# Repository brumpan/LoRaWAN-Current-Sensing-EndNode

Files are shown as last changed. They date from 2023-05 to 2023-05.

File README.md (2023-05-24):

# LoRaWAN-Current-Sensing-EndNode

Traditionally, remote monitoring has been done using wired communications technologies such as ethernet and fiberoptics. In the last decade, low power narrow band radio communications technologies, such as LoRaWAN, have enabled wireless remote monitoring in microgrids.  Installing remote monitoring systems can be very costly using both wired or wireless communication schemes. Wired connections are expensive during installation and wireless connections are expensive during operation due to service subscriptions and may also require pre-existing infrastructure to operate. This project provides a modular solution for monitoring power output from photovoltaic panels remotely.

This page contains the design files and software for a current-sensing end node for photovoltaic panels in microgrids using the LoRaWAN network.

# Dependencies

https://github.com/ElectronicCats/Beelan-LoRaWAN.git

https://github.com/earlephilhower/arduino-pico.git

# Credits

This project constitutes partial fulfillment of the Senior Project Capstone, a prerequisite for obtaining a Bachelor's degree in Electrical Engineering from The Oregon Institute of Technology.

Project Members: Brendan Dickerson & Leo Zenuhin

Spring 2023

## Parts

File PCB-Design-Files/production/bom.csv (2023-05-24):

Designator | Footprint | Quantity | Value | LCSC Part #
C1, C2 | 402 | 2 | 27p
C10, C12, C22, C23, C25, C26, C4, C6, C7, C9 | 402 | 10 | 100n
C11, C3, C8 | 402 | 3 | 2.2u
C13, C5 | 402 | 2 | 1u
C14, C16, C24 | 805 | 3 | 10u
C15 | 805 | 1 | 4.7u
C17, C18 | 402 | 2 | 1n
C19, C20 | 402 | 2 | 6.8n
C21 | 402 | 1 | 220n
C27 | CP_Elec_6.3x7.7 | 1 | 22u
D1, D3 | 805 | 2 | LED
D2, D4, D7, D8 | D_SOD-123 | 4 | B220
D6 | 805 | 1 | PWR
F1 | 805 | 1 | 6V 0.5A
Q1, Q2 | SOT-23 | 2 | BSS84
Q3 | SOT-23 | 1 | BSS123
R1, R10, R11, R22, R23, R6, R7, R8, R9 | 402 | 9 | 10k
R12 | 402 | 1 | 1.18k
R13 | 402 | 1 | 1.13k
R14 | R_Axial_DIN0411_L9.9mm_D3.6mm_P15.24mm_Horizontal | 1 | 220
R15, R16, R24 | 402 | 3 | 470
R17 | 402 | 1 | 100k
R18, R25, R4, R5 | 402 | 4 | 1k
R19_2 | 805 | 1 | 47
R19 | 402 | 1 | 47
R2, R3 | 402 | 2 | 27
R20, R21 | 402 | 2 | 4.7K
SW1 | SW_PUSH_6mm | 1 | Select
SW2 | SW_DIP_SPSTx08_Slide_6.7x21.88mm_W7.62mm_P2.54mm_LowProfile | 1 | SW_DIP_x08
SW3 | SW_PUSH_6mm | 1 | Bootsel
U1 | QFN-56-1EP_7x7mm_P0.4mm_EP3.2x3.2mm | 1 | RP2040
U2 | SOIC-16_3.9x9.9mm_P1.27mm | 1 | 74HC165
U3 | VQFN-16-1EP_3x3mm_P0.5mm_EP1.6x1.6mm | 1 | BQ24072RGT
U5 | SOIC-8_5.23x5.23mm_P1.27mm | 1 | W25Q128JVS
U6 | SOT-223-3_TabPin2 | 1 | AMS1117-3.3

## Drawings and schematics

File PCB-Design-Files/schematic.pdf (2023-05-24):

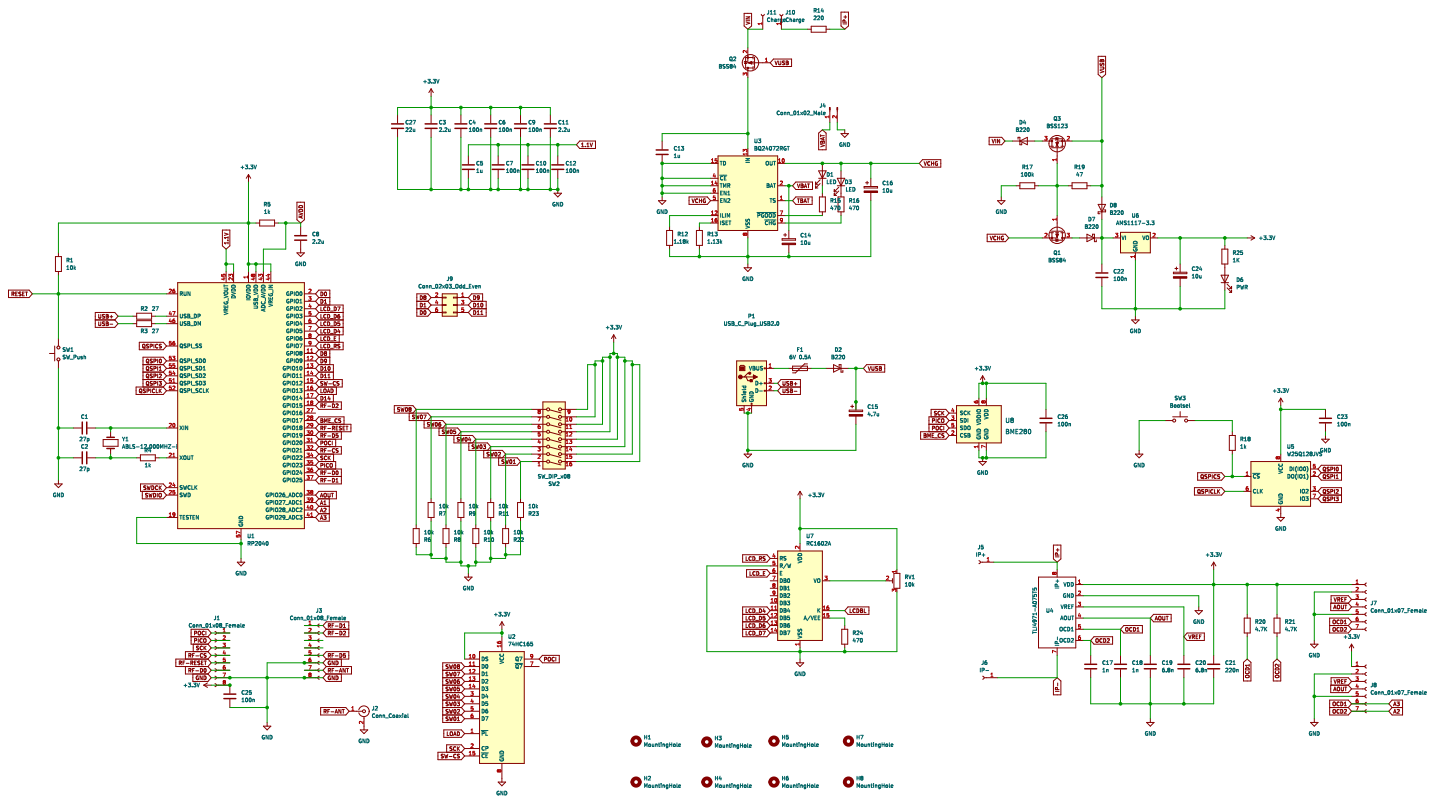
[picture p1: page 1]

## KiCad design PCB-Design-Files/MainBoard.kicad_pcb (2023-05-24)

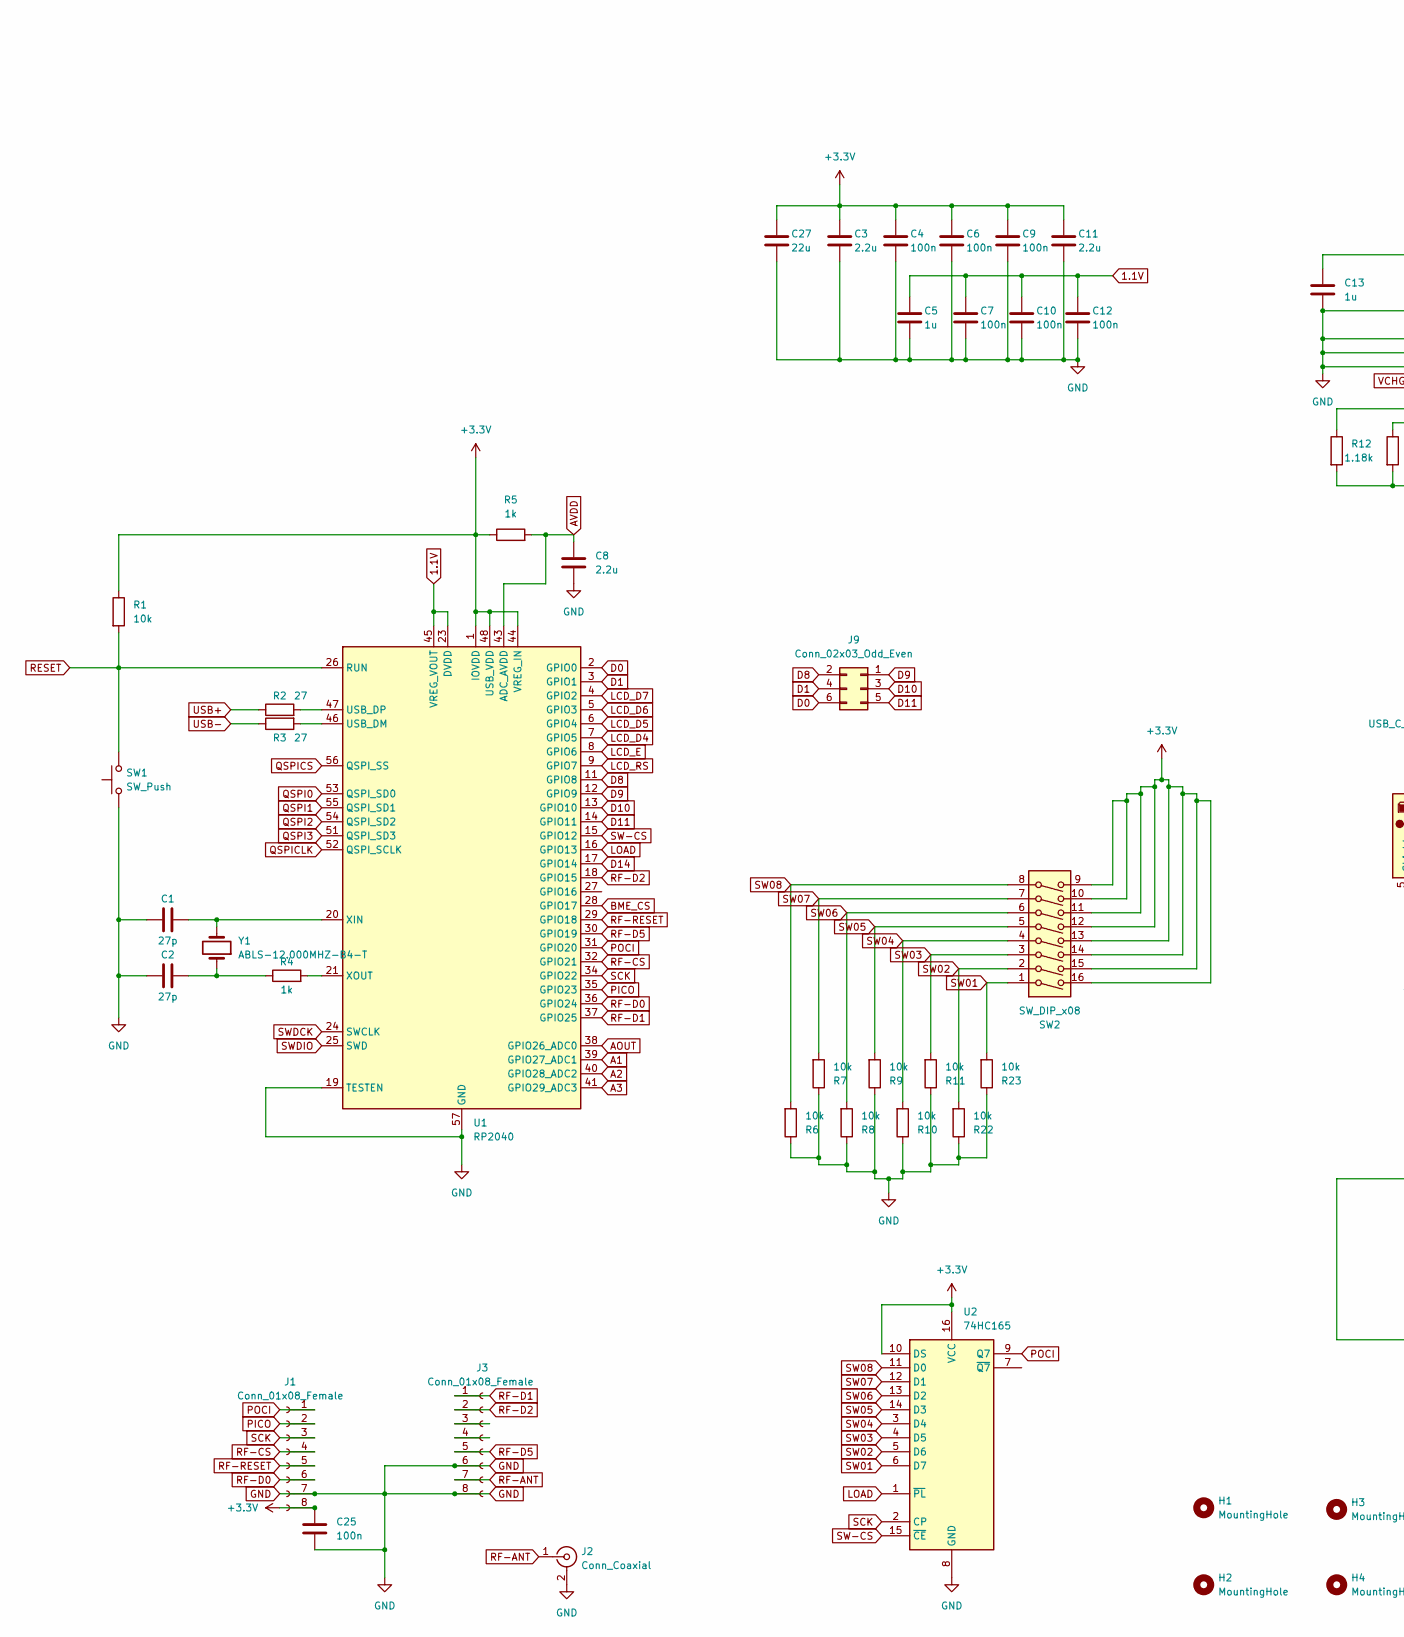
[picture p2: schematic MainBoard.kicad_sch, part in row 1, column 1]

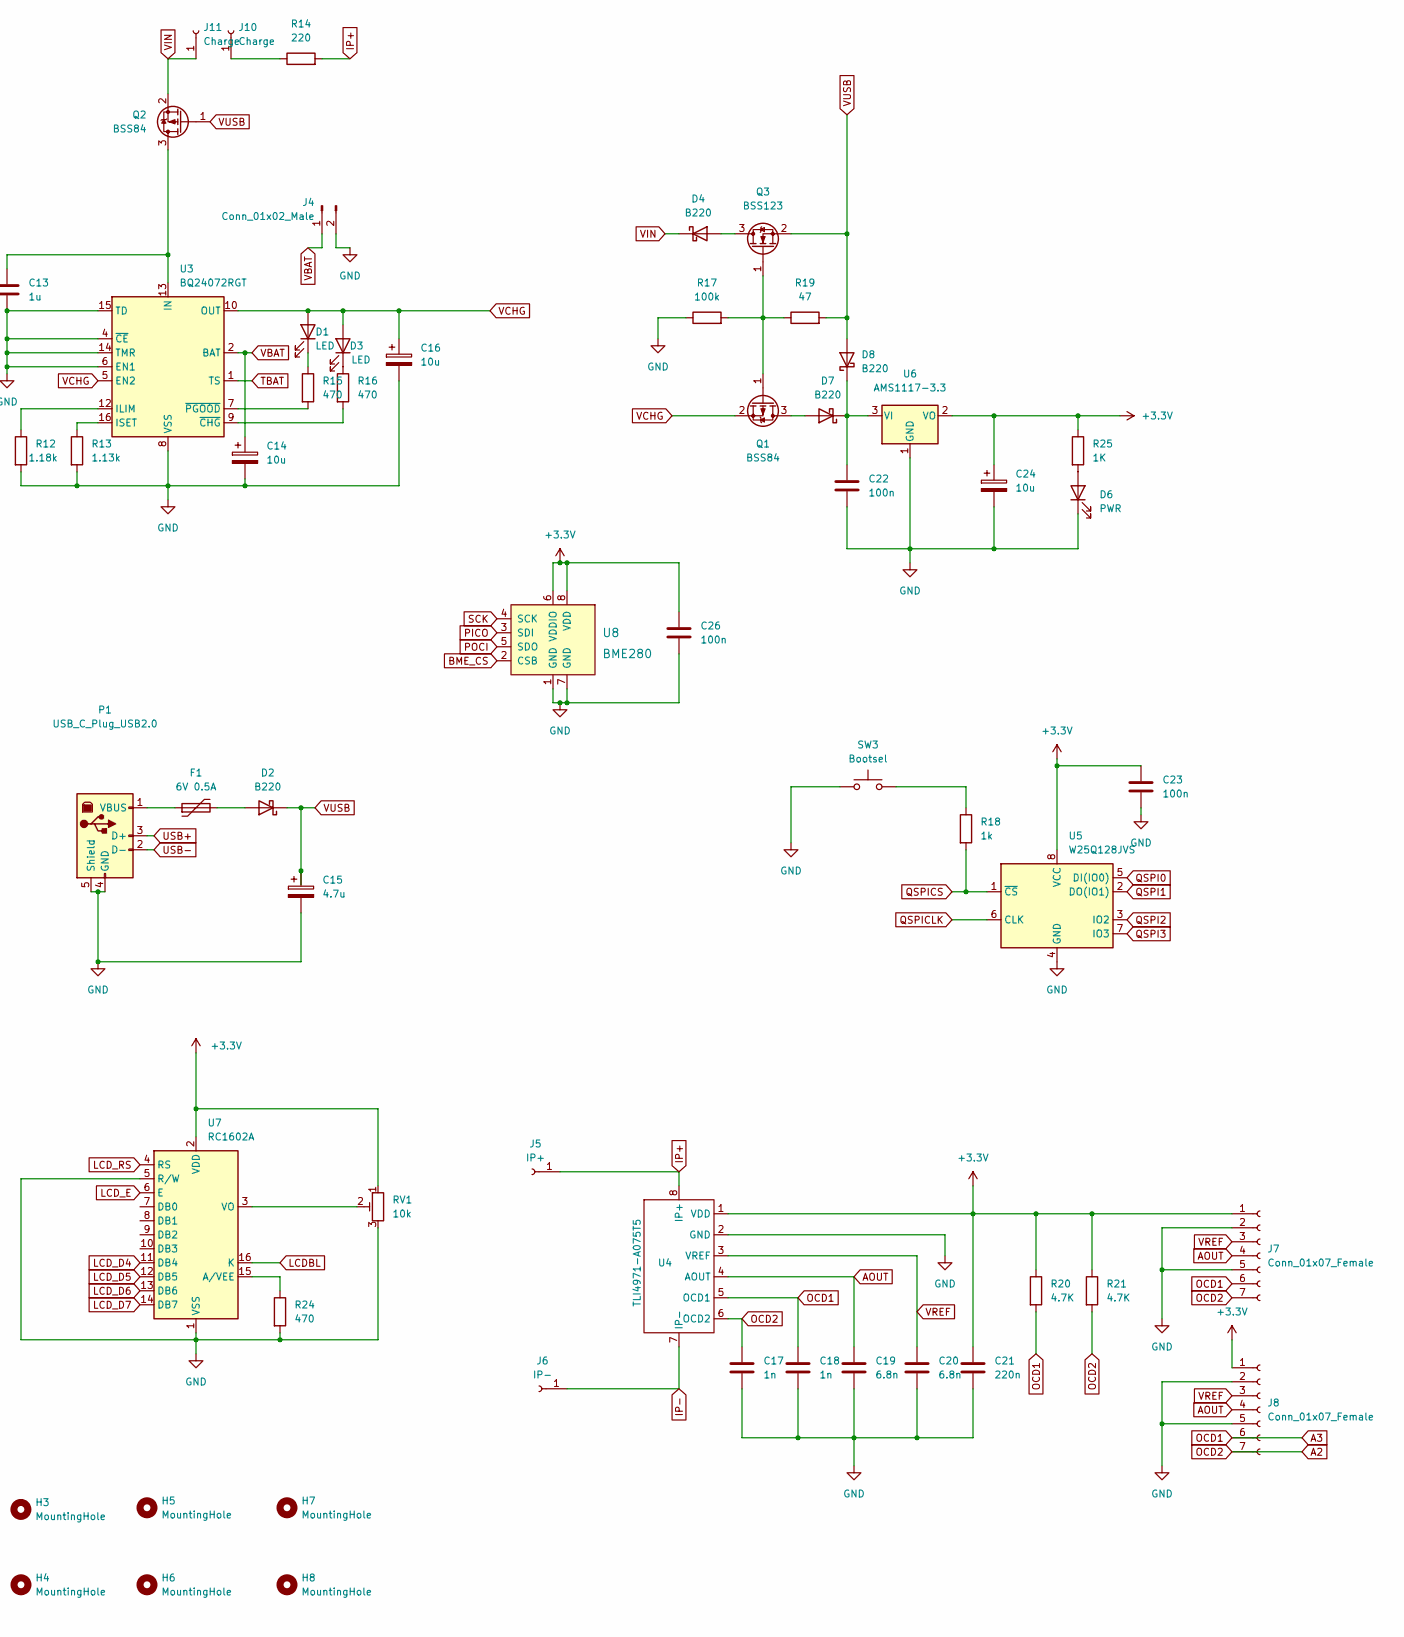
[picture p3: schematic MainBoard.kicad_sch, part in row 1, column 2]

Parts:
C1, C2: 27p; C_0402_1005Metric
C3, C8, C11: 2.2u; C_0402_1005Metric
C4, C6, C7, C9, C10, C12, C22, C23, C25, C26: 100n; C_0402_1005Metric
C5, C13: 1u; C_0402_1005Metric
C14, C16, C24: 10u; C_0805_2012Metric
C15: 4.7u; C_0805_2012Metric
C17, C18: 1n; C_0402_1005Metric
C19, C20: 6.8n; C_0402_1005Metric
C21: 220n; C_0402_1005Metric
C27: 22u; CP_Elec_6.3x7.7
D1, D3: LED; LED_0805_2012Metric
D2, D4, D7, D8: B220; D_SOD-123
D6: PWR; LED_0805_2012Metric
F1: 6V 0.5A; Fuse_0805_2012Metric
H1, H2, H3, H4, H5, H6, H7, H8: MountingHole; MountingHole_2.2mm_M2
J1, J3: Conn_01x08_Female; PinHeader_1x08_P2.54mm_Vertical
J2: Conn_Coaxial; U.FL_Molex_MCRF_73412-0110_Vertical
J4: Conn_01x02_Male; JST_PH_S2B-PH-K_1x02_P2.00mm_Horizontal
J5: IP+; Wuerth_REDCUBE-THR_WP-THRSH_74651195_THR
J6: IP-; Wuerth_REDCUBE-THR_WP-THRSH_74651195_THR
J7, J8: Conn_01x07_Female; PinHeader_1x07_P2.54mm_Vertical
J9: Conn_02x03_Odd_Even; PinSocket_2x03_P2.54mm_Vertical
J10, J11: Charge; PinSocket_1x01_P2.54mm_Vertical
P1: USB_C_Plug_USB2.0; USB_B_OST_USB-B1HSxx_Horizontal
Q1, Q2: BSS84; SOT-23
Q3: BSS123; SOT-23
R1, R6, R7, R8, R9, R10, R11, R22, R23: 10k; R_0402_1005Metric
R2, R3: 27; R_0402_1005Metric
R4, R5, R18: 1k; R_0402_1005Metric
R12: 1.18k; R_0402_1005Metric
R13: 1.13k; R_0402_1005Metric
R14: 220; R_Axial_DIN0617_L17.0mm_D6.0mm_P30.48mm_Horizontal
R15, R16, R24: 470; R_0402_1005Metric
R17: 100k; R_0402_1005Metric
R19: 47; R_0402_1005Metric
R20, R21: 4.7K; R_0402_1005Metric
R25: 1K; R_0402_1005Metric
RV1: 10k; Potentiometer_Bourns_3296Y_Vertical
SW1: SW_Push; SW_PUSH_6mm
SW2: SW_DIP_x08; SW_DIP_SPSTx08_Slide_6.7x21.88mm_W7.62mm_P2.54mm_LowProfile
SW3: Bootsel; SW_PUSH_6mm
U1: RP2040; QFN-56-1EP_7x7mm_P0.4mm_EP3.2x3.2mm
U2: 74HC165; SOIC-16_3.9x9.9mm_P1.27mm
U3: BQ24072RGT; VQFN-16-1EP_3x3mm_P0.5mm_EP1.6x1.6mm
U4: TLI4971-A075T5; Infineon_PG-TISON-8-5
U5: W25Q128JVS; SOIC-8_5.23x5.23mm_P1.27mm
U6: AMS1117-3.3; SOT-223-3_TabPin2
U7: RC1602A
U8: BME280; Pressure_Sensor_LGA-8_2.5x2.5mm_BME280; MPN BME280; Digi-Key_PN 828-1063-1-ND
Y1: ABLS-12.000MHZ-B4-T; Crystal_HC49-U_Vertical

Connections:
1.1V: C5.1, C7.1, C10.1, C12.1, U1.23 (DVDD), U1.45 (VREG_VOUT), U1.50 (DVDD)
+3.3V: C3.1, C4.1, C6.1, C9.1, C11.1, C21.1, C23.1, C24.1, C25.1, C26.1, C27.1, J1.8, J7.1, J8.1, R1.1, R5.1, R20.1, R21.1, R25.1, RV1.1, SW2.9, SW2.10, SW2.11, SW2.12, SW2.13, SW2.14, SW2.15, SW2.16, U1.1 (IOVDD), U1.10 (IOVDD), U1.22 (IOVDD), U1.33 (IOVDD), U1.42 (IOVDD), U1.44 (VREG_IN), U1.48 (USB_VDD), U1.49 (IOVDD), U2.10 (DS), U2.16 (VCC), U4.1 (VDD), U5.8 (VCC), U6.2 (VO), U7.2 (VDD), U8.6 (VDDIO), U8.8 (VDD); also elsewhere on the board
A1: U1.39 (GPIO27_ADC1)
A2: C17.1, J7.7, J8.7, R21.2, U1.40 (GPIO28_ADC2), U4.6 (OCD2)
A3: C18.1, J7.6, J8.6, R20.2, U1.41 (GPIO29_ADC3), U4.5 (OCD1)
AOUT: C19.1, J7.4, J8.4, U1.38 (GPIO26_ADC0), U4.4 (AOUT)
AVDD: C8.1, R5.2, U1.43 (ADC_AVDD)
BME_CS: U1.28 (GPIO17), U8.2 (CSB)
D0: J9.6, U1.2 (GPIO0)
D1: J9.4, U1.3 (GPIO1)
D8: J9.2, U1.11 (GPIO8); also elsewhere on the board
D9: J9.1, U1.12 (GPIO9)
D10: J9.3, U1.13 (GPIO10)
D11: J9.5, U1.14 (GPIO11)
D14: U1.17 (GPIO14)
IP+: J5.1, R14.2, U4.8 (IP+)
IP-: J6.1, U4.7 (IP-)
LCDBL: U7.16 (K)
LCD_D4: U1.7 (GPIO5), U7.11 (DB4)
LCD_D5: U1.6 (GPIO4), U7.12 (DB5)
LCD_D6: U1.5 (GPIO3), U7.13 (DB6)
LCD_D7: U1.4 (GPIO2), U7.14 (DB7)
LCD_E: U1.8 (GPIO6), U7.6 (E)
LCD_RS: U1.9 (GPIO7), U7.4 (RS)
LOAD: U1.16 (GPIO13), U2.1 (~PL)
unnamed: C1.2, U1.20 (XIN), Y1.2
unnamed: C2.2, R4.1, Y1.1
unnamed: C13.1, Q2.3 (D), U3.13 (IN)
unnamed: C22.1, D7.1 (K), D8.1 (K), U6.3 (VI)
unnamed: D1.1 (K), R15.1
unnamed: D2.2 (A), F1.2
unnamed: D3.1 (K), R16.1
unnamed: D4.2 (A), Q3.3 (D)
unnamed: D6.2 (A), R25.2
unnamed: D7.2 (A), Q1.3 (D)
unnamed: F1.1, P1.1 (VBUS)
unnamed: J10.1, R14.1
unnamed: R2.2, U1.47 (USB_DP)
unnamed: R3.2, U1.46 (USB_DM)
unnamed: R4.2, U1.21 (XOUT)
unnamed: R12.1, U3.12 (ILIM)
unnamed: R13.1, U3.16 (ISET)
unnamed: R15.2, U3.7 (~PGOOD)
unnamed: R16.2, U3.9 (~CHG)
unnamed: R18.1, SW3.2
unnamed: R24.1, U7.15 (A/VEE)
unnamed: RV1.2, U7.3 (VO)
PICO: J1.2, U1.35 (GPIO23), U8.3 (SDI)
POCI: J1.1, U1.31 (GPIO20), U2.9 (Q7), U8.5 (SDO)
QSPI0: U1.53 (QSPI_SD0), U5.5 (DI(IO0))
QSPI1: U1.55 (QSPI_SD1), U5.2 (DO(IO1))
QSPI2: U1.54 (QSPI_SD2), U5.3 (IO2)
QSPI3: U1.51 (QSPI_SD3), U5.7 (IO3)
QSPICLK: U1.52 (QSPI_SCLK), U5.6 (CLK)
QSPICS: R18.2, U1.56 (QSPI_SS), U5.1 (~CS)
RESET: R1.2, SW1.2, U1.26 (RUN)
RF-ANT: J2.1 (In), J3.7
RF-CS: J1.4, U1.32 (GPIO21)
RF-D0: J1.6, U1.36 (GPIO24)
RF-D1: J3.1, U1.37 (GPIO25)
RF-D2: J3.2, U1.18 (GPIO15)
RF-D5: J3.5, U1.30 (GPIO19)
RF-RESET: J1.5, U1.29 (GPIO18)
SCK: J1.3, U1.34 (GPIO22), U2.2 (CP), U8.4 (SCK)
SW01: R23.2, SW2.1, U2.6 (D7)
SW02: R22.2, SW2.2, U2.5 (D6)
SW03: R11.2, SW2.3, U2.4 (D5)
SW04: R10.2, SW2.4, U2.3 (D4)
SW05: R9.2, SW2.5, U2.14 (D3)
SW06: R8.2, SW2.6, U2.13 (D2)
SW07: R7.2, SW2.7, U2.12 (D1)
SW08: R6.2, SW2.8, U2.11 (D0)
SW-CS: U1.15 (GPIO12), U2.15 (~CE)
SWDCK: U1.24 (SWCLK)
SWDIO: U1.25 (SWD)
TBAT: U3.1 (TS)
USB+: P1.3 (D+), R2.1
USB-: P1.2 (D-), R3.1
VBAT: C14.1, J4.1, U3.2 (BAT), U3.3 (BAT)
VCHG: C16.1, D1.2 (A), D3.2 (A), Q1.2 (S), U3.5 (EN2), U3.10 (OUT), U3.11 (OUT)
VREF: C20.1, J7.3, J8.3, U4.3 (VREF)

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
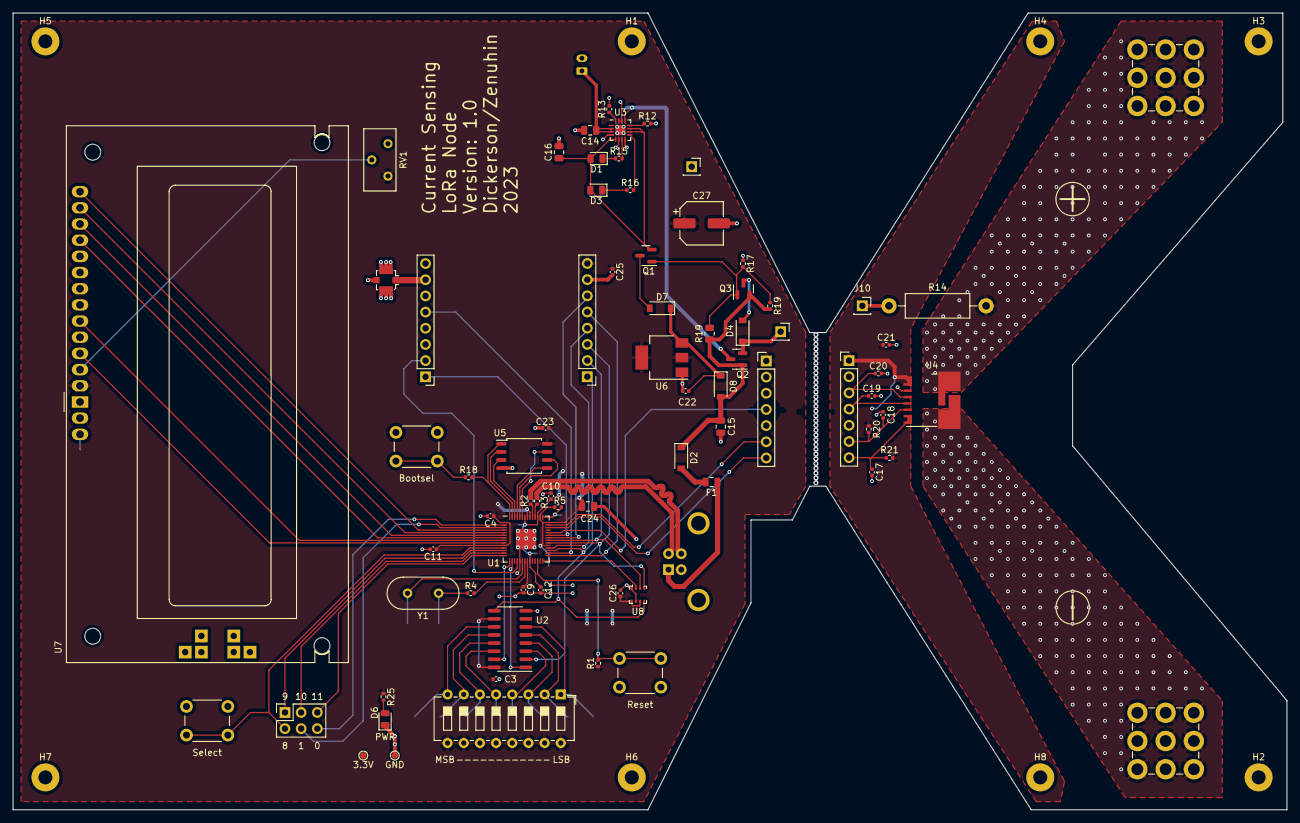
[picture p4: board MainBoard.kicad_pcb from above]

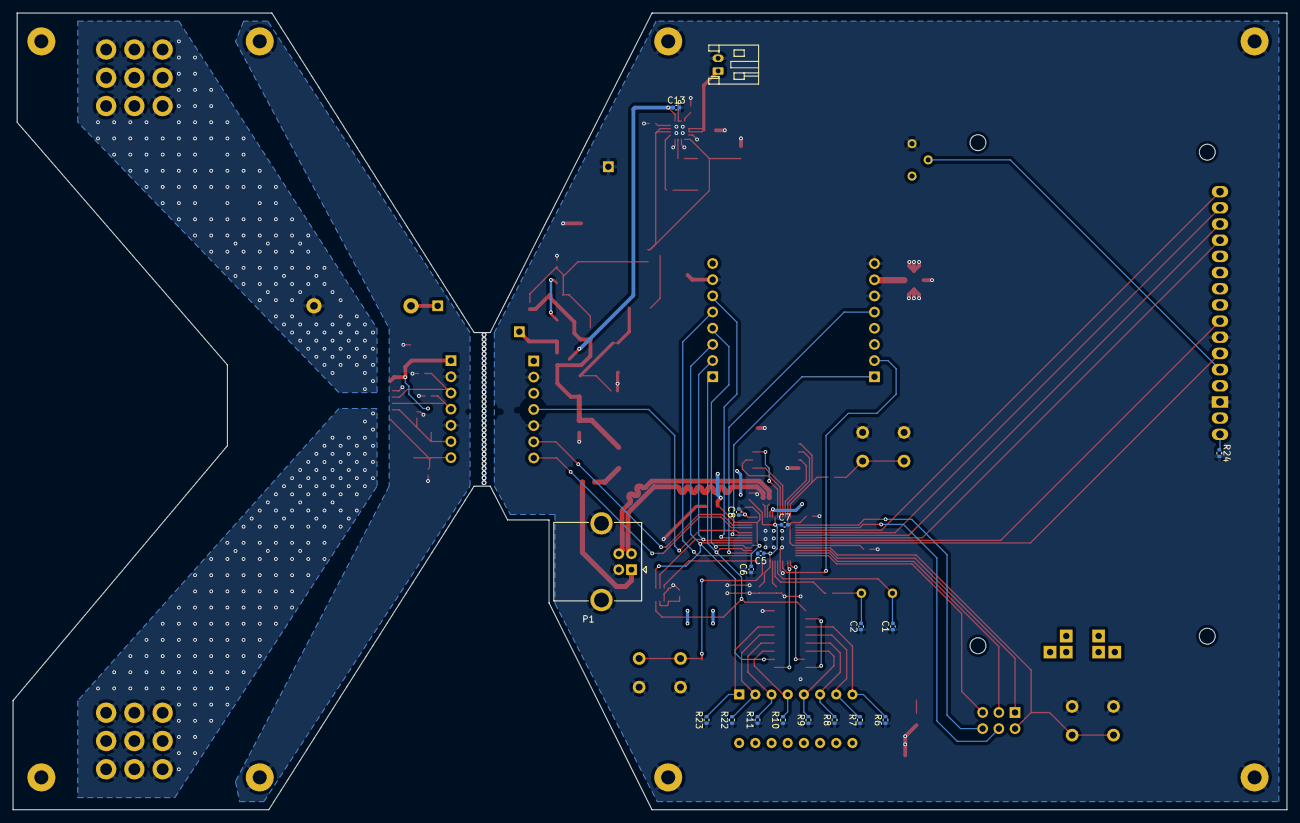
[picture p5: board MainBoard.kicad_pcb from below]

Board: 2 copper layers, 200.0 x 125.1 mm, 101 parts (18 on the bottom side), 79 nets.

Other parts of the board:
3.3V: TestPoint_Pad_D1.0mm
GND: TestPoint_Pad_D1.0mm
J11#2: Charge; PinSocket_1x01_P2.54mm_Vertical
R19#2: 47; R_0402_1005Metric
SW1#2: Select; SW_PUSH_6mm

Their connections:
+3.3V: 3.3V.1; also elsewhere on the board
D8: SW1#2.1; also elsewhere on the board

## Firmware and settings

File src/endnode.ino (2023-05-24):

#include <Adafruit_BME280.h>
#include <LiquidCrystal.h>
#include <lorawan.h>
#include <SPI.h>
#include <TLI4971.h>

/***************************************************************

- File:   endnode.ino
- Author: Brendan Dickerson
- Date:   2023-05-31
- Course: Capstone Project Spring 2023
- School: Oregon Institue of Technology
- Description:
    End node takes an analog current reading, environment status,
    and additional information and transmits it back to a 
    LoraWAN gateway. Typical applications for this include
    remote alternative energy sources such as photovoltaic 
    installations or wind energy farms. 

****************************************************************/

// RP2040 pin definitions
#define D0      0
#define D1      1
#define LCD_D7  2
#define LCD_D6  3
#define LCD_D5  4
#define LCD_D4  5
#define LCD_E   6
#define LCD_RS  7
#define SELBTN  8
#define TXLED   9
#define LCDBL   10
#define D11     11
#define SW_CS   12
#define LOAD    13
#define D14     14
#define RF_D2   15
#define BME_CS  17
#define RF_RES  18
#define RF_D5   19
#define POCI    20
#define RF_CS   21
#define SCK     22
#define PICO    23
#define RF_D0   24
#define RF_D1   25
#define CURRENT A0
#define VREF    A2
#define OCD1    A3


// //LCD Display
// LiquidCrystal lcd(LCD_RS, LCD_E, LCD_D4, LCD_D5, LCD_D6, LCD_D7);
// bool displayActive = false;

// //BME280
// //Adafruit_BME280 bme(BME_CS, POCI, PICO, SCK);
// long temp = 0;
// long humidity = 0;

//ABP Credentials 
const char *devAddr = "10101010";
const char *nwkSKey = "00000000000000000000000000000000";
const char *appSKey = "00000000000000000000000000000000";

//Timing for transmission
const unsigned long interval = 10000;    // interval to send message
unsigned long previousMillis = 0;  // will store last time message sent
unsigned int counter = 0;     // message counter

//Storage for current calculation
int current = 0;
int avg,ref = 0;

//Storage for transmission data
char data[2] = {0, 1};
byte recvStatus = 0;

//Pinout for RFM95
const sRFM_pins RFM_pins = {
  .CS = RF_CS,
  .RST = RF_RES,
  .DIO0 = RF_D0,
  .DIO1 = RF_D1,
  .DIO2 = RF_D2,
  .DIO5 = RF_D5,
};

/******************
  Setup Function
******************/
void setup() {
  Serial.begin(9600);
  delay(100);
  //while(!Serial);
  loraSetup();
  //bmeSetup();
  //lcd.begin(16, 2);

  pinMode(LCDBL, OUTPUT);
  pinMode(VREF, INPUT);
  pinMode(CURRENT, INPUT);
  pinMode(TXLED, OUTPUT);
  analogWrite(VREF, 1028);
}

/*******************
  Loop Function
*******************/
void loop() {
  transmit();
  digitalWrite(TXLED, LOW);
  digitalWrite(LCDBL, HIGH);
}

/*******************
  Read TLI4971
*******************/
void getCurrent() {
  avg = 0;
  for(int i = 0; i<500; i++) {
    analogRead(CURRENT);
    avg += analogRead(CURRENT);
  }
  avg = avg/500.0;
  
  ref = 0;
  for(int i = 0; i<500; i++) {
    analogRead(VREF);
    ref += analogRead(VREF);
  }
  ref = ref/500.0;
  
  current = round(((avg-ref)/6));
}

/*******************
  LoRa Transmit
*******************/
void transmit() {
  // Check interval overflow
  if(millis() - previousMillis > interval) {
    //getEnvironment();
    getCurrent();
    Serial.println(current);
    digitalWrite(TXLED, HIGH);
    digitalWrite(LCDBL, HIGH);
    //lcd.clear();
    //lcd.print("Transmitting...");
    previousMillis = millis(); 
    data[0] = current;     //change to current
    Serial.print("Sending: ");
    Serial.println((int)data[0]);

    lora.sendUplink(data, strlen(data), 0, 1);
    counter++;
  }
  lora.update(); //needed 
}

/*******************
  LoRa Setup/Config
*******************/
void loraSetup() {
  while(!lora.init()){
    Serial.println("RFM95 not detected");
    delay(1000);
  }
  Serial.println("Starting...");
  
  // Set LoRaWAN Class change CLASS_A or CLASS_C
  lora.setDeviceClass(CLASS_A);

  // Set Data Rate
  lora.setDataRate(SF9BW125);
  
  // set channel to random
  lora.setChannel(MULTI);
  
  // Put ABP Key and DevAddress here
  lora.setNwkSKey(nwkSKey);
  lora.setAppSKey(appSKey);
  lora.setDevAddr(devAddr);
  lora.setDevEUI("00000000");
}

/*******************
  Setup BME280
*******************/
// void bmeSetup() {
//     unsigned status;
//     // default settings
//    // status = bme.begin();  
//     // You can also pass in a Wire library object like &Wire2
//     // status = bme.begin(0x76, &Wire2)
//     if (!status) {
//         Serial.println("Could not find a valid BME280 sensor, check wiring, address, sensor ID!");
//         Serial.print("SensorID was: 0x"); Serial.println(bme.sensorID(),16);
//         Serial.print("        ID of 0xFF probably means a bad address, a BMP 180 or BMP 085\n");
//         Serial.print("   ID of 0x56-0x58 represents a BMP 280,\n");
//         Serial.print("        ID of 0x60 represents a BME 280.\n");
//         Serial.print("        ID of 0x61 represents a BME 680.\n");
//         while (1) delay(10);
//     }
// }

/*******************
  Read BME280
*******************/
// void getEnvironment() {
//   //temp = bme.readTemperature();
//   Serial.print("Temperature = ");
//   Serial.print(temp);
//   Serial.println(" °C");
    
//   humidity = bme.readHumidity();
//   Serial.print("Humidity = ");
//   Serial.print(humidity);
//   Serial.println(" %");
// }

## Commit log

2023-05-24 Board files for Arduino IDE
2023-05-24 PCB Design Files in KiCAD
    [MainBoard.kicad_pcb, MainBoard.kicad_sch, bom.csv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]
2023-05-24 Arduino program file for board
2023-05-24 Custom board files for end node
